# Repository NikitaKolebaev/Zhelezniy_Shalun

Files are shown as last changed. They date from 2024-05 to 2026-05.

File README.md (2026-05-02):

# Zhelezniy_Shalun
## 1. Preview
Arduino based bot with radio control. The challenge we had accepted consisted of 
few reglament instructions. In our project, it was prohibited to use round wheels 
to accelerate the bot. So, our team decided to use tracks instead. We emphasized 
the idea behind the design, which was inspired by the automotive industry. 
You can find out that people living in cold areas, like Sibir, are using some 
special car tracks to navigate through difficult terrain.

<p align="center">
  Example of car tracks construction
  <br>
  <em>Example of car tracks construction</em>
</p>

## 2. Mechanical construction
Below you can see a photo of our robot's assembly, which shows some of the main structural components. 
Construction contains:
* The main body
* DC motor x2
* Wheelbase with gear, 8 rolls x2
* Track x2
* Rail
* Battery pack power supply
* The crown battery
* Arduino Uno 
* Motor Sheild
* Radio module RF24
* RGB LED matrix
* Servo
* Power supply tumbler

<p align="center">
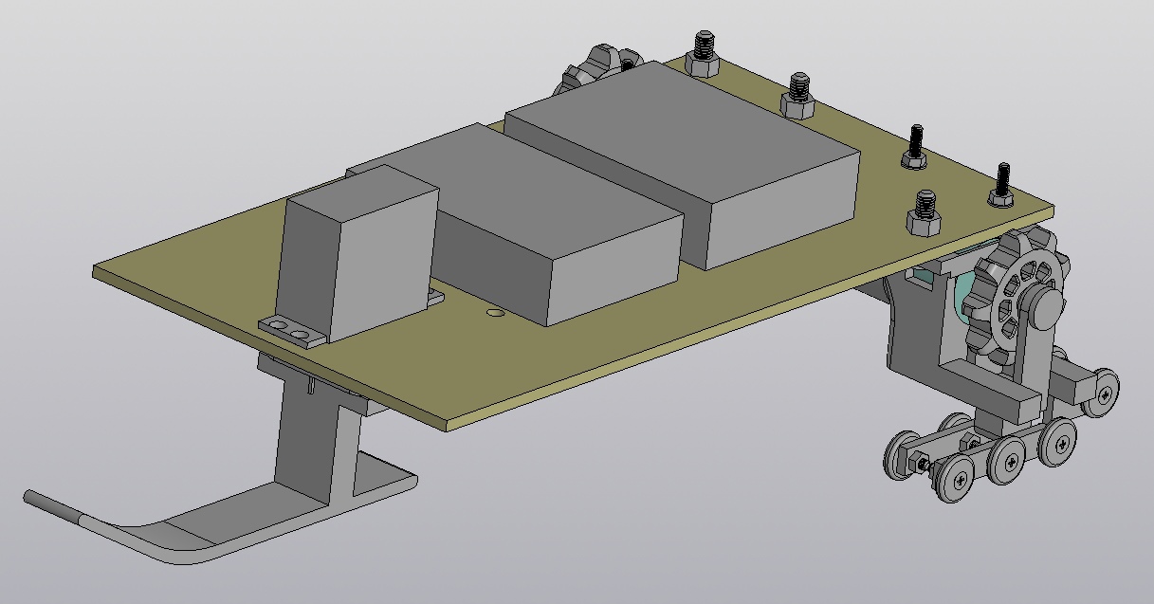
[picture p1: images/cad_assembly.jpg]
  
  <br>
  <em>CAD assembly in Compass3D</em>
</p>

<p align="center">
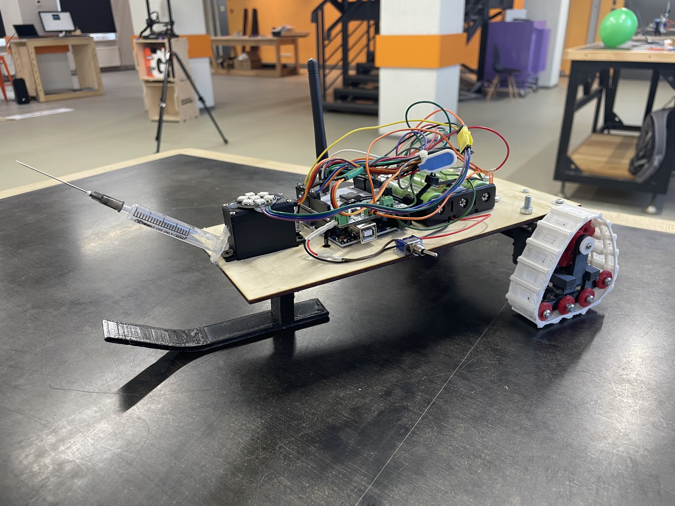
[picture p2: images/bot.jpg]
  
  <br>
  <em>Photo of the real bot</em>
</p>

## 3. Controller navigation
To navigate our bot we used to create a special controller. Here you can see a list of all the components we 
have in the construction of the controller:
* Controller body (consists of 2 parts: the top and the bottom)
* Sticks to provide the structural strength
* Arduino Uno
* Radio module RF24
* Power supply tumbler
* The crown battery
* Potentiometer
* LED tumbler
* joystick-module to navigate through the vertiacal axis
* joystick-module to navigate through the horizontal axis

Here you can see the photo of complited controller and the script to maintain.

<p align="center">
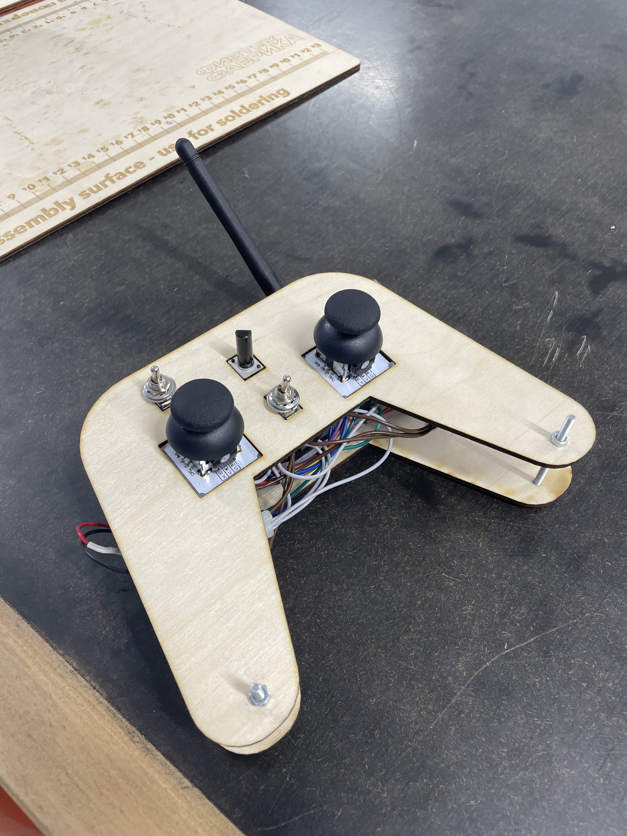
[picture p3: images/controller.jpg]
Controller
  
  <br>
  <em>Photo of the real bot</em>
</p>

```C++
#include <SPI.h>
#include <nRF24L01.h>
#include <RF24.h>

RF24 radio(8, 9); // CE, CSN
int data[4];  

const int xPin = A1; //0-540-1023
const int yPin = A0; //0-496-1023
//const int buttonPin = 4;
const int ptmrPin = A2; //0-1023
const int tumblrPin = 4;

int x_pos = 0;
int y_pos = 0;
int buttonState = 0;
int tumblrState = 0;
int ptmr = 0;
int for_back_dir = 0;
                                
void setup(){
    radio.begin();
    radio.setChannel(16);
    radio.setDataRate(RF24_1MBPS);  
    radio.setPALevel(RF24_PA_HIGH);
    radio.openWritingPipe(0xABABCC1766LL);
    pinMode(xPin, INPUT);
    pinMode(yPin, INPUT);
    //pinMode(buttonPin, INPUT_PULLUP);
    pinMode(tumblrPin, INPUT_PULLUP);
    pinMode(ptmrPin, INPUT);
}
void loop() {
    x_pos = analogRead(xPin);
    y_pos = analogRead(yPin);
    //buttonState = digitalRead(buttonPin);
    tumblrState = digitalRead(tumblrPin);
    ptmr = analogRead(ptmrPin);

    if (y_pos > 540){
      //forward
      for_back_dir = 1;
      //message = "forward";
    }
    else if (y_pos < 450){
      //backward
      for_back_dir = -1;
      //message = "backward";
    }
    else{
      //stop
      //message = "stop";
      for_back_dir = 0;
    }

    data[0] = for_back_dir;
    data[1] = x_pos;
    data[2] = ptmr;
    data[3] = tumblrState;
    //data[4] = buttonState;

    radio.write(&data, sizeof(data));
    delay(10);
}
```

## 4. Bot script
```C++
//#include <SPI.h>
#include <nRF24L01.h>
#include <RF24.h>
#include <Servo.h>
//Приемник (робот)

#define SPEED_1      5 
#define DIR_1        4
 
#define SPEED_2      6
#define DIR_2        7

RF24 radio(8, 9); // CE, CSN
Servo servo;
int data[4];
int angle;
// for_back_dir, x_pos, ptmr, tumblrState

void setup() {
  Serial.begin(9600);
  servo.attach(2);

  for (int i = 4; i < 8; i++) {     
    pinMode(i, OUTPUT);
  }

  radio.begin();
  radio.setChannel(16);
  radio.setDataRate(RF24_1MBPS);
  radio.setPALevel(RF24_PA_HIGH);
  radio.openReadingPipe(0, 0xABABCC1766LL);
  radio.startListening();
}
void loop() {
  if (radio.available()) {
    radio.read(&data, sizeof(data));
    angle = map(data[1], 0, 1023, 45, 135);
    servo.write(angle);
    //Serial.println(servo.read());

    if (data[0] == 1){
      digitalWrite(DIR_1, HIGH);
      digitalWrite(DIR_2, HIGH);
      if (angle < 60){
        analogWrite(SPEED_2, data[2] - (data[2] / 3));
        analogWrite(SPEED_1, data[2]);
      }
      else if (angle > 120){
        analogWrite(SPEED_2, data[2]);
        analogWrite(SPEED_1, data[2] - (data[2] / 3));
      }
      else{
        analogWrite(SPEED_1, data[2]);
        analogWrite(SPEED_2, data[2]);
      }
    }
    else if (data[0] == -1){
      digitalWrite(DIR_1, LOW);
      digitalWrite(DIR_2, LOW);
      if (angle < 60){
        analogWrite(SPEED_2, data[2] - (data[2] / 3));
        analogWrite(SPEED_1, data[2]);
      }
      else if (angle > 120) {
        analogWrite(SPEED_2, data[2]);
        analogWrite(SPEED_1, data[2] - (data[2] / 3));
      }
      else{
        analogWrite(SPEED_1, data[2]);
        analogWrite(SPEED_2, data[2]);
      }
    }
    else {
      analogWrite(SPEED_1, 0);
      analogWrite(SPEED_2, 0);
    }
    //print_info(data[0], angle, data[2], data[3]);
    delay(2);
  }
}
/*
void print_info(int y, int angle, int ptmr, int tmbl) {
    Serial.print("y = ");
    Serial.print(y);
    Serial.print(", angle = ");
    Serial.print(angle);
    Serial.print(", ptmr = ");
    Serial.print(ptmr);
    Serial.print(", tmbl = ");
    Serial.println(tmbl);
}*/
```

## 5. Награждение
Данный проект был создан в рамках студенческого соревнования от МФТИ под
названием "Fab-bots" (февраль-май 2024 г.). Созданная нашей командой модель робота успешно выполнила все
задания от организаторов и заняла первое место. В качестве приза наша команда получила 3D-принтер 
Creality Ender-3 V3 SE.

<p align="center">
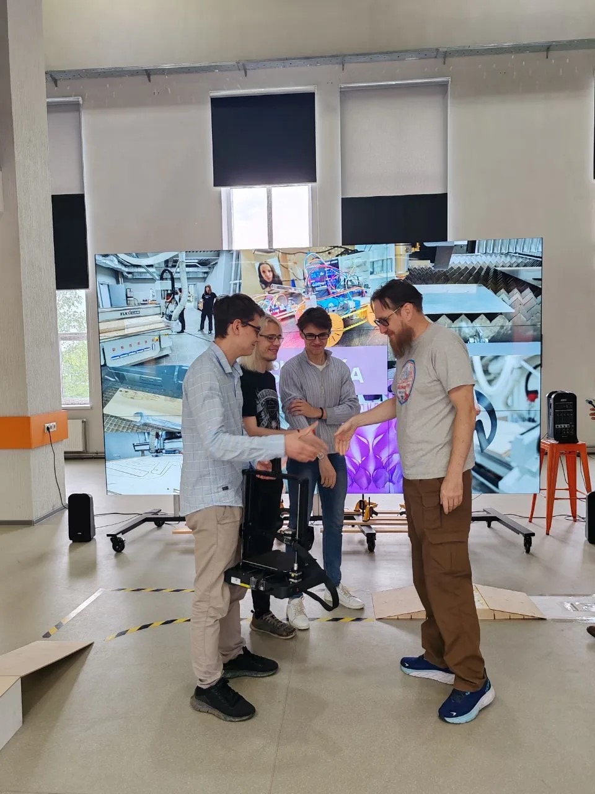
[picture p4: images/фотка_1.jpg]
  
  <br>
  <em>Фото с награждения</em>
</p>

<p align="center">
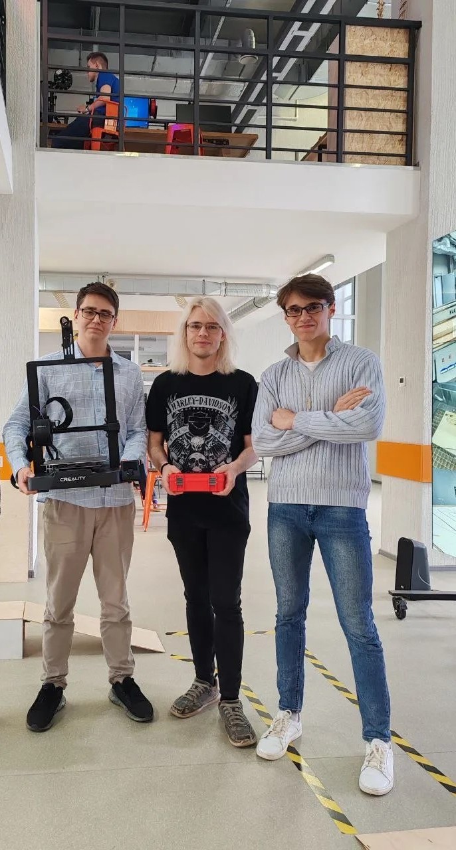
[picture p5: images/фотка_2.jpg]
  
  <br>
  <em>Фото с награждения</em>
</p>

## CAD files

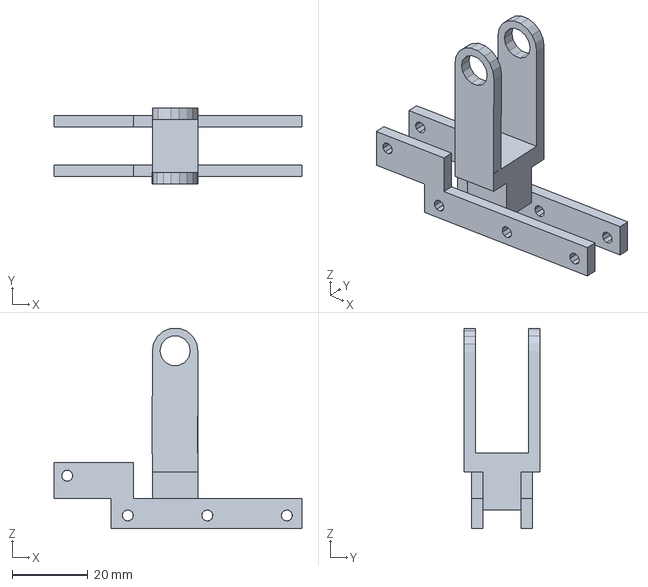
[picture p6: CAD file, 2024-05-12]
CAD/Wheelbase.3mf
65.5 x 20.0 x 52.9 mm

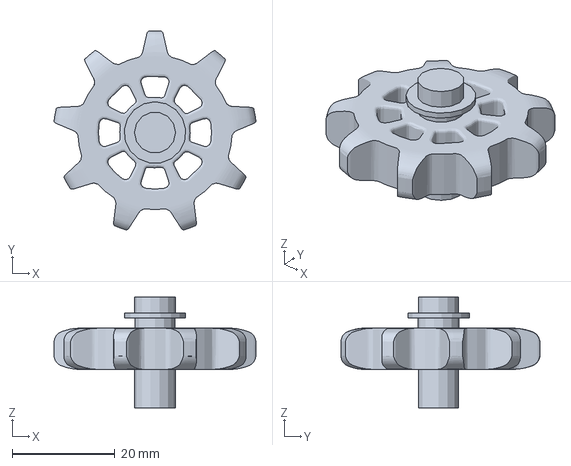
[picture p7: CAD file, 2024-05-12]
CAD/Gear.3mf
39.3 x 38.8 x 21.5 mm

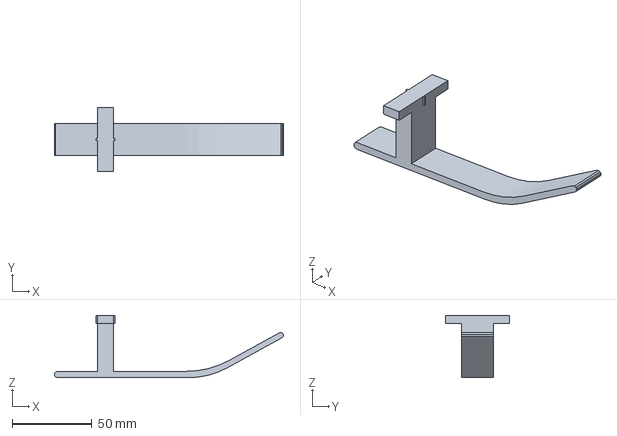
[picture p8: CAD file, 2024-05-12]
CAD/Rail.3mf
143.3 x 40.0 x 39.0 mm

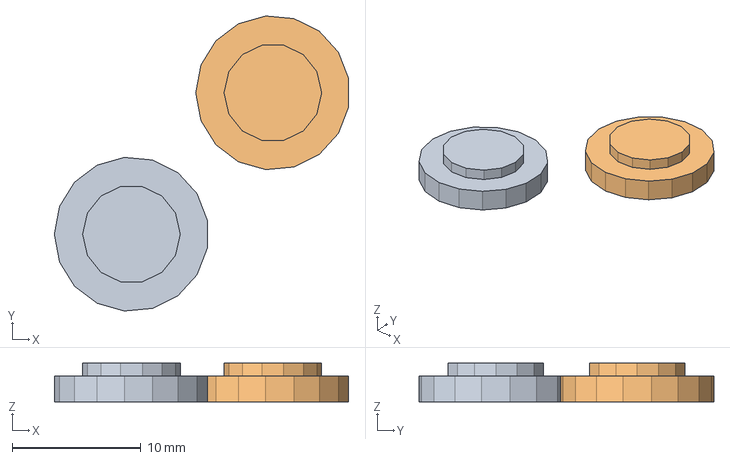
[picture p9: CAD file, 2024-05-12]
CAD/Zatichka_2.3mf
22.9 x 22.9 x 3.00 mm
Затычка_2.stl x 2

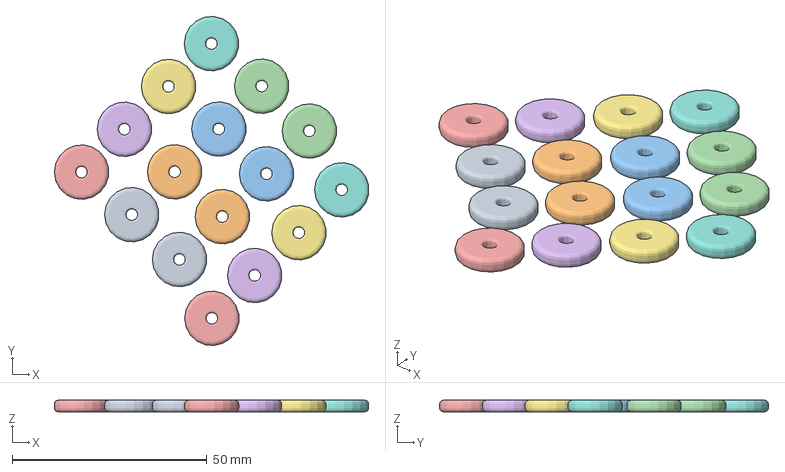
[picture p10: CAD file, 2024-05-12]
CAD/Wheels.3mf
80.7 x 84.5 x 3.00 mm
колесо_actual.stl x 16

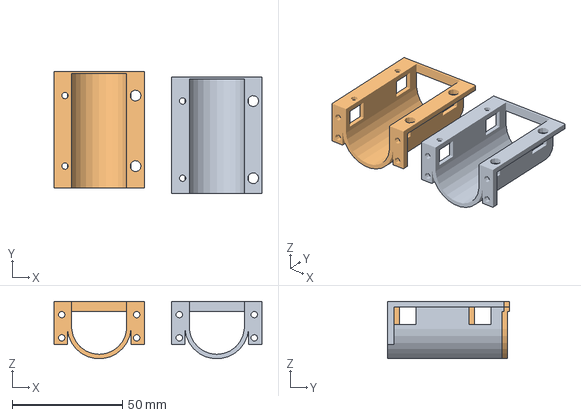
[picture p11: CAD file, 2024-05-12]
CAD/Engine_body.3mf
94.4 x 55.5 x 25.9 mm
Корпус двигателя (правый).stl
Корпус двигателя (левый).stl

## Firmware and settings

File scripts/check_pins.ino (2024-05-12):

#include <SPI.h>

const int xPin = A1; //0-540-1023
const int yPin = A0; //0-496-1023
//const int buttonPin = 4;
const int ptmrPin = A2; //0-1023
const int tumblrPin = 4;


void setup() {
  Serial.begin(9600);
  pinMode(xPin, INPUT);
  pinMode(yPin, INPUT);
  //pinMode(buttonPin, INPUT_PULLUP);
  pinMode(tumblrPin, INPUT);
  pinMode(ptmrPin, INPUT);
}

void loop() {
  int x_value = analogRead(xPin);
  int y_value = analogRead(yPin);
  int tumblState = digitalRead(tumblrPin);
  int ptmr = analogRead(ptmrPin); 
  Serial.print("x = ");
  Serial.print(x_value);
  Serial.print(", y = ");
  Serial.print(y_value);
  Serial.print(", bt = ");
  Serial.print(tumblState);
  Serial.print(", ptmr = ");
  Serial.println(ptmr);
}

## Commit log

2024-05-12 add almost all cad-files
    [Engine_body.3mf, Gear.3mf, Rail.3mf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]
2024-05-12 add LED functions
